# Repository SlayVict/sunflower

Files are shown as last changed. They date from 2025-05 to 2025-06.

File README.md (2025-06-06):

# Sunflower

Corne like keyboard I made to tinker with ergogen. Case model is not ready to share



## Components

- khail choc brown
- nice! nano v2
- Li POI 301230 batteries
- batteries connector I honestly don't know the name of
- Reset Switch SPID 4-pin Flat
- Power Switch - Micro SMD SPOT
- khail choc hotswap sockets

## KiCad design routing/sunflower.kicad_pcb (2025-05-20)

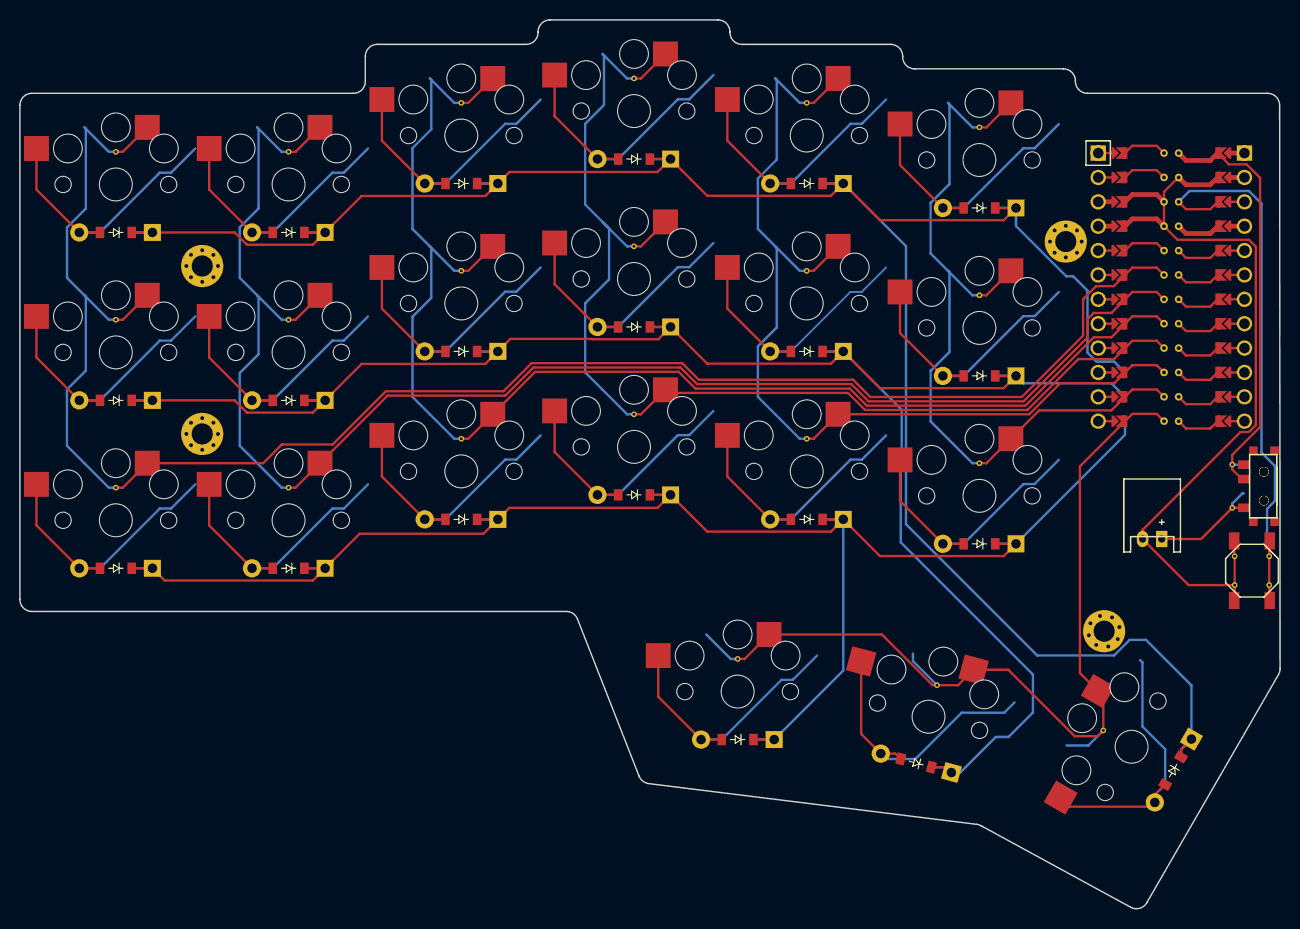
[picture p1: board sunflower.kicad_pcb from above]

Board: 2 copper layers, 131.3 x 92.6 mm, 52 parts (0 on the bottom side), 34 nets.

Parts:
B1, B2: SW_TACT_ALPS_SKQGABE010
D1, D2, D3, D4, D5, D6, D7, D8, D9, D10, D11, D12, D13, D14, D15, D16, D17, D18, D19, D20, D21: ComboDiode
JST1: JST_PH_S2B-PH-K_02x2.00mm_Angled
MCU1: ProMicro
S1, S2, S3, S4, S5, S6, S7, S8, S9, S10, S11, S12, S13, S14, S15, S16, S17, S18, S19, S20, S21: PG1350
T1, T2: SPDT_C128955
_28, _29, _30, _31: MountingHole_2.2mm_M2_Pad_Via

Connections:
GND: B1.1, B2.1, JST1.2, MCU1.2, MCU1.21, MCU1.22
P3: MCU1.19, S1.1, S2.1, S3.1
P4: MCU1.18, S4.1, S5.1, S6.1
P5: MCU1.17, S7.1, S8.1, S9.1
P6: MCU1.16, S10.1, S11.1, S12.1
P7: MCU1.15, S13.1, S14.1, S15.1
P8: MCU1.14, S16.1, S17.1, S18.1
P9: MCU1.13, S19.1, S20.1, S21.1
P10: D1.1, D4.1, D7.1, D10.1, D13.1, D16.1, D19.1, MCU1.12
P14: D3.1, D6.1, D9.1, D12.1, D15.1, D18.1, D21.1, MCU1.10
P16: D2.1, D5.1, D8.1, D11.1, D14.1, D17.1, D20.1, MCU1.11
RAW: JST1.1, MCU1.1, T1.1, T1.2, T2.1, T2.2
RST: B1.2, B2.2, MCU1.3
cozy_default: D19.2, S19.2
index_bottom: D13.2, S13.2
index_home: D14.2, S14.2
index_top: D15.2, S15.2
inner_bottom: D16.2, S16.2
inner_home: D17.2, S17.2
inner_top: D18.2, S18.2
middle_bottom: D10.2, S10.2
middle_home: D11.2, S11.2
middle_top: D12.2, S12.2
pinky2_bottom: D4.2, S4.2
pinky2_home: D5.2, S5.2
pinky2_top: D6.2, S6.2
pinky_bottom: D1.2, S1.2
pinky_home: D2.2, S2.2
pinky_top: D3.2, S3.2
reachy_default: D21.2, S21.2
ring_bottom: D7.2, S7.2
ring_home: D8.2, S8.2
ring_top: D9.2, S9.2
tucky_default: D20.2, S20.2

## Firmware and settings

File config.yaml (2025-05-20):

# U is a predefined unit of measure that means 19.05mm, which is MX spacing
units:
  # Proxy Spacing Variables
  kx: cx # 18mm Choc X spacing
  ky: cy # 17mm Choc Y spacing
  # Padding Variables
  px: 1
  py: px
  fil: 1.25
  dpx: 4
  dpy: 4
  screwSize: 1.5
points:
  key:
    padding: 1ky+0.5
    spread: 1kx
  zones:
    matrix:
      #anchor:
      #  shift: [100, -100]

      columns:
        pinky:
          key.column_net: P3
          key.tags:
            regulal:
        pinky2:
          key.column_net: P4
          key.tags:
            regulal:
        ring:
          key.column_net: P5
          key.stagger: 0.3ky
          key.tags:
            regulal:
        middle:
          key.column_net: P6
          key.stagger: 0.15ky
          #key.spread: 1.3ky
          key.tags:
            regulal:
        index:
          key.column_net: P7
          key.stagger: -0.15ky
          key.tags:
            regulal:
        inner:
          key.column_net: P8
          key.stagger: -0.15ky
          key.tags:
            regulal:
      rows:
        bottom:
          row_net: P10
        home:
          row_net: P16
        top:
          row_net: P14
    thumb:
      anchor:
        ref: matrix_middle_bottom
        shift: [0.6kx, -1.50ky]
      columns:
        cozy:
          key.column_net: P9
          key.name: thumb_cozy
          key.row_net: P10
          key.tags:
            regulal:
        tucky:
          key.column_net: P9
          key.name: thumb_tucky
          key.row_net: P16
          key.spread: kx
          key.splay: -15
          key.origin: [-0.5kx, -0.5ky]
          key.tags:
            regulal:
        reachy:
          key.column_net: P9
          key.name: thumb_reachy
          key.row_net: P14
          key.splay: -15
          key.shift: [0kx, 0.25ky+1]
          key.origin: [-0.5kx, -0.5ky]
          key.rotate: 90
          key.width: 1.5kx
          key.tags:
            bigger:
  #rotate: -15
  #mirror: &mirror
  #  ref: thumb_reachy
  #  distance: 3kx

outlines:
  _raw:
    - what: rectangle
      where: true
      size: [px, py]
      bound:
      fillet: fil
    - what: rectangle
      where: bigger
      bound:
      size: [1.5px, py]
      fillet: fil

  board:
    - what: polygon
      operation: stack
      points:
        - ref: matrix_pinky_top
          shift: [-0.5kx-px, 0.5ky+py]
        - ref: matrix_pinky2_top
          shift: [0.5kx-px, 0.5ky+py]
        - ref: matrix_ring_top
          shift: [-0.5kx-px, 0.5ky+py]
        - ref: matrix_ring_top
          shift: [0.5kx-px, 0.5ky+py]
        - ref: matrix_middle_top
          shift: [-0.5kx-px, 0.5ky+py]
        - ref: matrix_middle_top
          shift: [0.5kx+px, 0.5ky+py]
        - ref: matrix_index_top
          shift: [-0.5kx+px, 0.5ky+py]
        - ref: matrix_index_top
          shift: [0.5kx+px, 0.5ky+py]
        - ref: matrix_inner_top
          shift: [-0.5kx+px, 0.5ky+py]
        - ref: matrix_inner_top
          shift: [0.5kx+px, 0.5ky+py]
        - ref: matrix_inner_top
          shift: [-0.5kx+kx+px, 0.5ky-0.15ky+py]
        - ref: matrix_inner_top
          shift: [0.5kx+kx+1.45+1.834201+px, 0.5ky-0.15ky+py]
        - ref: thumb_reachy
          shift: [0.75kx+px, -0.5ky-py]
        - ref: thumb_reachy
          shift: [-0.75kx-px, -0.5ky-py]
        - ref: thumb_tucky
          shift: [0.5kx-px, -0.5ky-py]
        - ref: thumb_cozy
          shift: [-0.5kx-px, -0.5ky-py]
        - ref: matrix_pinky2_bottom
          shift: [1.6kx+px, -0.5ky-py]
        #- ref: matrix_pinky2_bottom
        #  shift: [0.5kx+px,-0.5ky-py]
        - ref: matrix_pinky_bottom
          shift: [-0.5kx-px, -0.5ky-py]
      fillet: fil

  _mounting:
    - what: circle
      radius: screwSize
      where:
        ref: [matrix_pinky_top]
        shift: [0.5kx, -0.5ky]
    - what: circle
      radius: screwSize
      where:
        ref: [matrix_pinky_home]
        shift: [0.5kx, -0.5ky]
    - what: circle
      radius: screwSize
      where:
        ref: [matrix_inner_top]
        shift: [0.5kx, -0.5ky]
    - what: circle
      radius: screwSize
      where:
        ref: [thumb_reachy]
        shift: [0.5kx, 0.5ky]

  circuitboard:
    - name: board
    - operation: stack
      name: _mounting

  _keycaps_outline:
    - what: rectangle
      where: regulal
      bound: false
      size: [kx-0.5, ky-0.5]
  _keycaps_outline15:
    - what: rectangle
      where: bigger
      bound: false
      size: [1.5kx-0.5, ky-0.5]
  keycaps: [_keycaps_outline, _keycaps_outline15]

  keyboard:
    - name: board
    - operation: stack
      name: keycaps
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

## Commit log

2025-05-20 remove extra footprints
2025-05-20 updated config to create dxf with mounting holes for future use in fusion
2025-05-20 fixed routing for F (qwerty) key
    [sunflower.kicad_pcb]
